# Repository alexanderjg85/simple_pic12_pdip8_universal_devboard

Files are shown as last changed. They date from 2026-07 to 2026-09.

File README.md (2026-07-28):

# simple_pic12_pdip8_universal_devboard
A simple development board with an LED and GPIOs on Pin headers. Includes an ICSP Header and selectable dual power supply with a screw terminal

## Project Structure
- **/hardware**: Contains the KiCad schematic and PCB layout files.
- **/firmware**: Contains the Microchip MPLAB  C/ASM source code.

## Programming Notes
- Designed for all **PIC12 8-PDIP Variants with Flashmemory** microcontrollers.
- Programmed using **Microchip MPLAB** and an **PicKit 2/3** programmer. 
- *Note:* The PicKit Programmer can power the board. Make sure to choose appropriate Voltage 3.3 V or 5V and make sure that the board is jumpered correctly, if powered by external power supply. 

## License / Lizenz

This project is dual-licensed / Dieses Projekt ist dual-lizenziert:

* **Hardware (Schematic, PCB Layout):** Licensed under the [CERN Open Hardware Licence Version 2 - Permissive (CERN-OHL-P)](LICENSE_HARDWARE.md).
* **Software (Firmware, Example Code):** Licensed under the [MIT License](LICENSE).

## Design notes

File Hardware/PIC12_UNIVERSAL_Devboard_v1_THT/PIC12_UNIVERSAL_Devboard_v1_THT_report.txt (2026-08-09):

PCB statistics report
=====================
- Date: Sun 09 Aug 2026 13:23:43 CEST
- Project: PIC12_UNIVERSAL_Devboard_v1_THT
- Board name: PIC12_UNIVERSAL_Devboard_v1_THT

Board
-----
- Width: 70.0000 mm
- Height: 40.0000 mm
- Area: 2800.00 mm²
- Front copper area: 365.793 mm²
- Back copper area: 2592.249 mm²
- Min track clearance: 0.3600 mm
- Min track width: 0.3000 mm
- Min drill diameter: 0.4500 mm
- Board stackup thickness: 1.6000 mm

- Front footprint area: 781.65 mm²
- Back footprint area: 147.625 mm²
- Front component density: 27.92 %
- Back component density: 5.27 %
Pads
----
- Through hole: 34
- SMD: 46
- Connector: 0
- NPTH: 4
- Castellated: 0
- Press-fit: 0

Vias
----
- Through vias: 36
- Blind vias: 0
- Buried vias: 0
- Micro vias: 0

Components
----------

| | Front Side | Back Side | Total |
|---|---|---|---|
|THT: | 7 | 0 | 7 |
|SMD: | 15 | 0 | 15 |
|Unspecified:  | 17 | 0 | 17 |
|Total: | 39 | 0 | 39 |

Drill holes
-----------

| Count | Shape | X Size | Y Size | Plated | Via/Pad | Start Layer | Stop Layer |
|---|---|---|---|---|---|---|---|
| 27 | Round | 0.5000 mm | 0.5000 mm | PTH | Via | F.Cu | B.Cu |
| 16 | Round | 1.0000 mm | 1.0000 mm | PTH | Pad | F.Cu | B.Cu |
| 12 | Round | 0.8000 mm | 0.8000 mm | PTH | Pad | F.Cu | B.Cu |
| 9 | Round | 0.4500 mm | 0.4500 mm | PTH | Via | F.Cu | B.Cu |
| 4 | Round | 2.7000 mm | 2.7000 mm | NPTH | Pad | F.Cu | B.Cu |
| 4 | Round | 0.9000 mm | 0.9000 mm | PTH | Pad | F.Cu | B.Cu |
| 2 | Round | 1.3000 mm | 1.3000 mm | PTH | Pad | F.Cu | B.Cu |

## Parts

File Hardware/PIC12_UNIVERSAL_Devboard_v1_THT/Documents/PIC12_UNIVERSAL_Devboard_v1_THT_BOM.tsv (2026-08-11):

Reference | Qty | Value | Spec | Package | LCSC | MFR PN
C1,C3,C4 | 3 | 1 uF | ±10% 50V | 0805 | C6119929
C2 | 1 | 470nF | ±10% 50V | 0805 | C13967
C5 | 1 | 100nF | ±10% 50V | 0805 | C49678
D1,D4 | 2 | SS14 | 30V 0.5A Schottky Diode | SMA | C2480
D2 | 1 | GREEN | LED GREEN | 3 mm
D3 | 1 | YELLOW | LED YELLOW | 3 mm
J2 | 1 | Conn_PIC_ICSP_ICD | Male / THT/ Vertical | 2.54 mm 1x6
J3 | 1 | Screw_Terminal_01x02 | Horizontal | 5.08mm 1x2
J4 | 1 | Conn_01x07_Pin | Male / THT/ Vertical | 2.54 mm 1x7
JP1 | 1 | JP_PLED | Male / THT/ Vertical | 2.54 mm 1x2
JP2 | 1 | Jumper_3_Open | Male / THT/ Vertical | 2.54 mm 1x3
JP3 | 1 | JP_SLED | Male / THT/ Vertical | 2.54 mm 1x2
R1 | 1 | 680 | 1% 125 mW | 1206
R2,R4 | 2 | 10k | 1% 125 mW | 1206
R3 | 1 | 330 | 1% 125 mW | 1206
SW1 | 1 | SW_RESET | H=4.5mm Tactile | 4.5 x 4.5 SMD |  | SWT0210-045026GSA
U1 | 1 | PIC12F617-xP | 8-Bit PIC 20 Mhz | PDIP-8 |  | PIC12F17I/P
U2 | 1 | 78L05G-AB3-R | 5V 0.1 A | SOT-89-3 | C71136
U3 | 1 | XC6206-3.3V_C3015484 | 3.3V 0.25A | SOT23 | C3015484
U4 | 1 | SI2301-A1SHB | P-Mos 20V 2.3A | SOT23 | C28642376 | SI2301-A1SHB

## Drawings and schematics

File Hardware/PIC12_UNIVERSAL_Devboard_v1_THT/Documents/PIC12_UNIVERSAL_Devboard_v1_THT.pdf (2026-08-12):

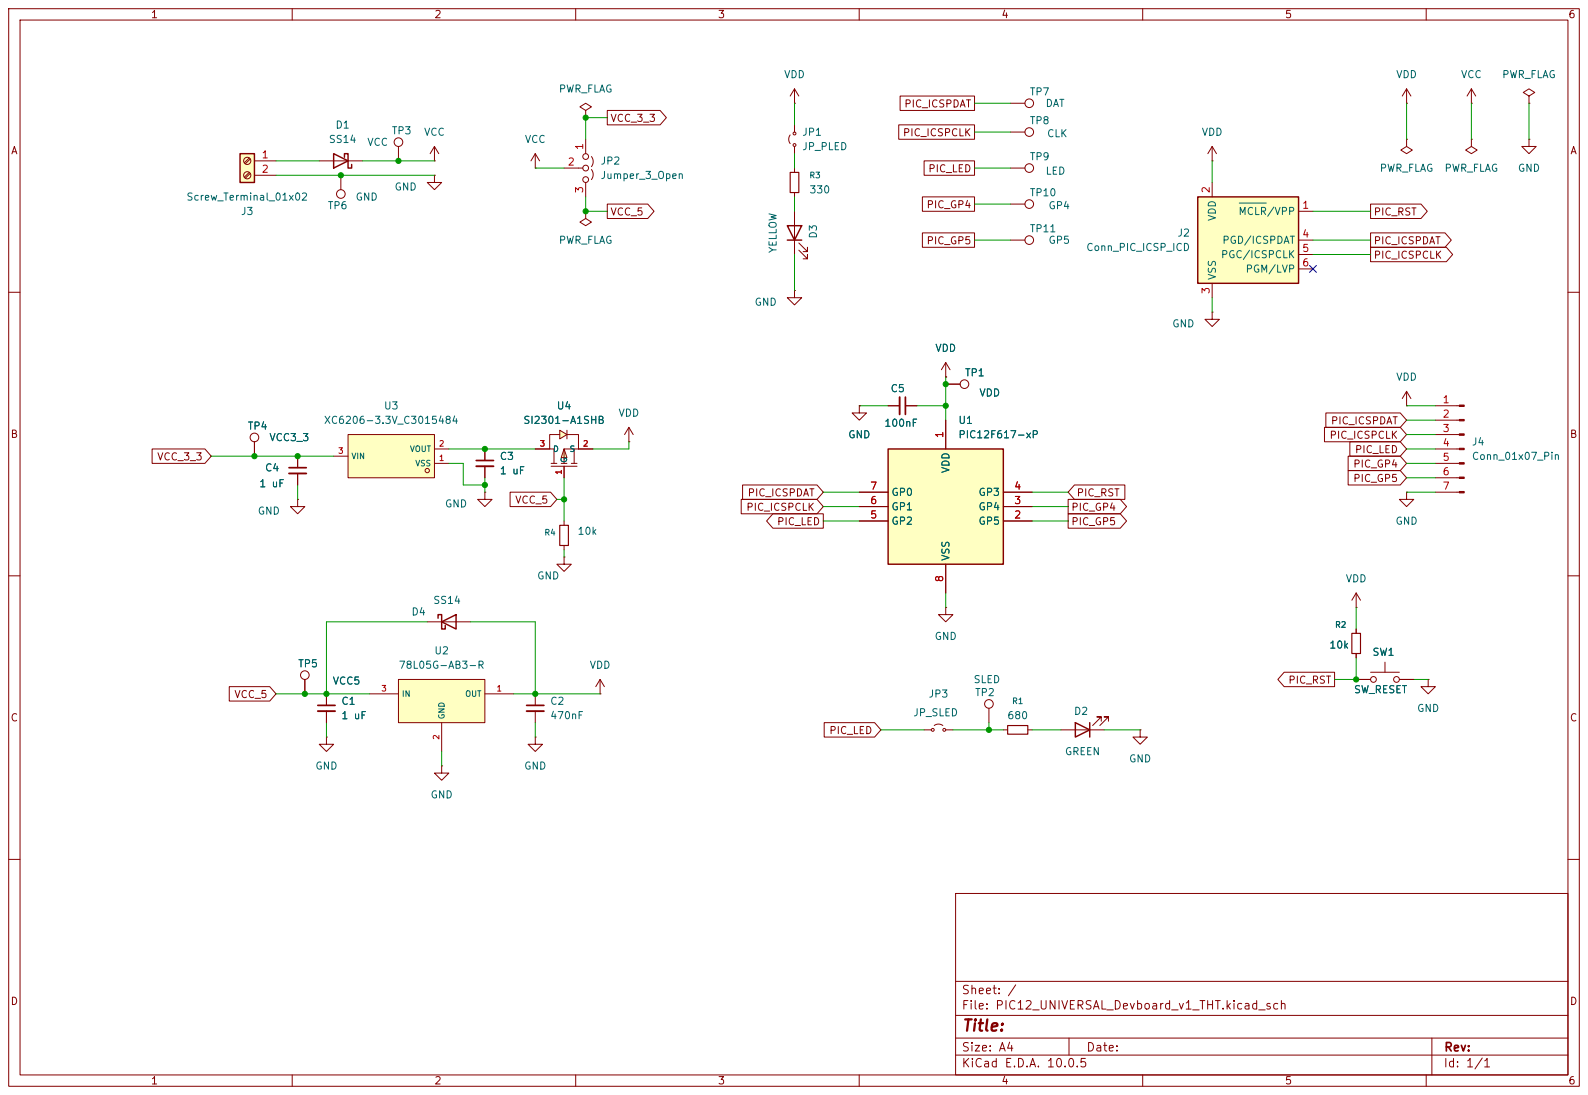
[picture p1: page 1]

3 PGD/ICSPDAT 4 PGC/ICSPCLK 5 PGM/LVP 6

Size: A4 | Rev:
KiCad E.D.A. 10.0.5 | Id: 1/1

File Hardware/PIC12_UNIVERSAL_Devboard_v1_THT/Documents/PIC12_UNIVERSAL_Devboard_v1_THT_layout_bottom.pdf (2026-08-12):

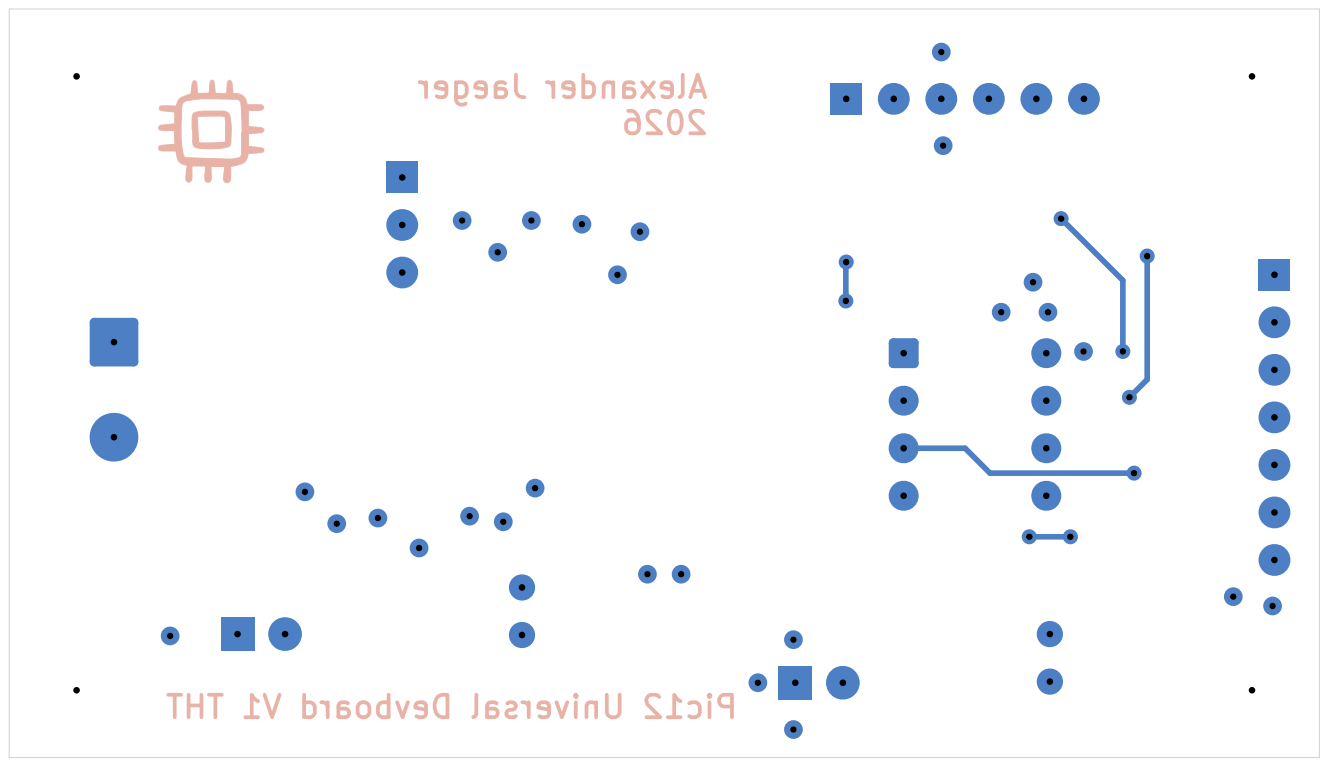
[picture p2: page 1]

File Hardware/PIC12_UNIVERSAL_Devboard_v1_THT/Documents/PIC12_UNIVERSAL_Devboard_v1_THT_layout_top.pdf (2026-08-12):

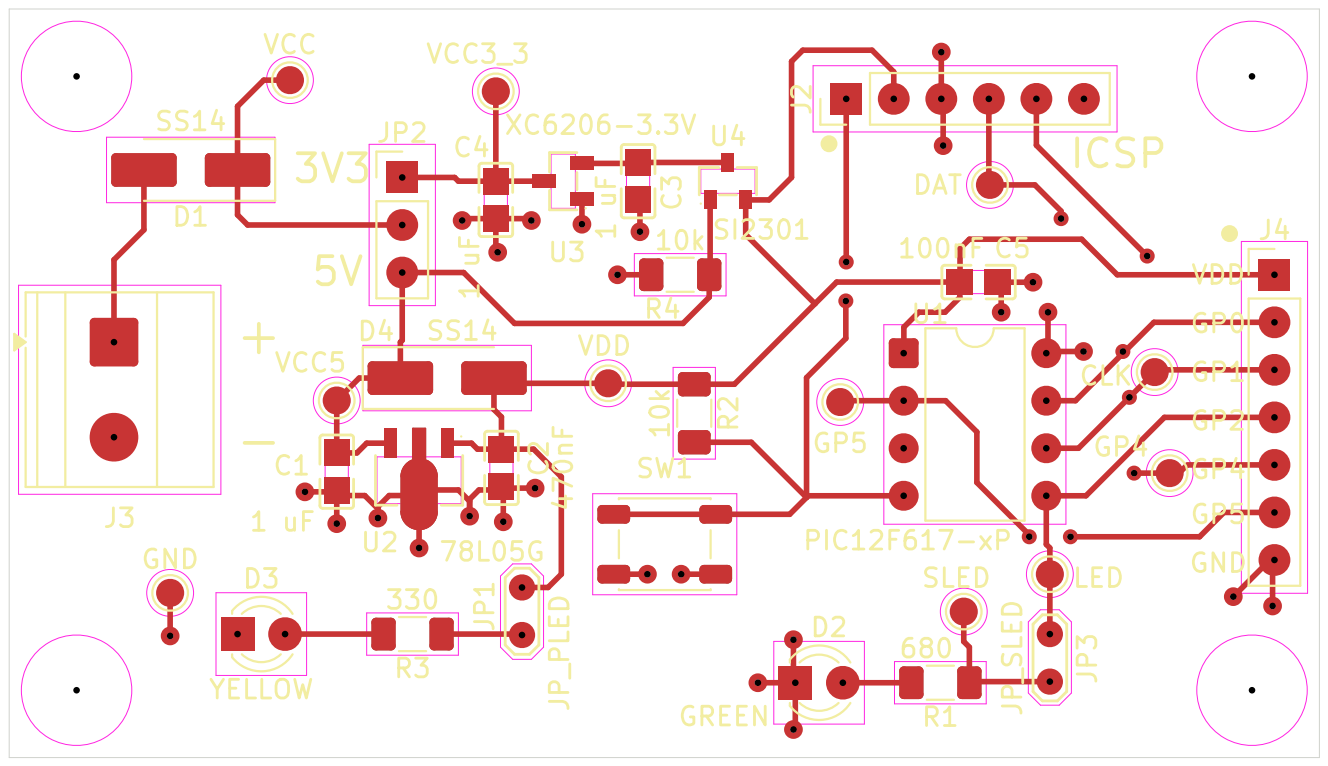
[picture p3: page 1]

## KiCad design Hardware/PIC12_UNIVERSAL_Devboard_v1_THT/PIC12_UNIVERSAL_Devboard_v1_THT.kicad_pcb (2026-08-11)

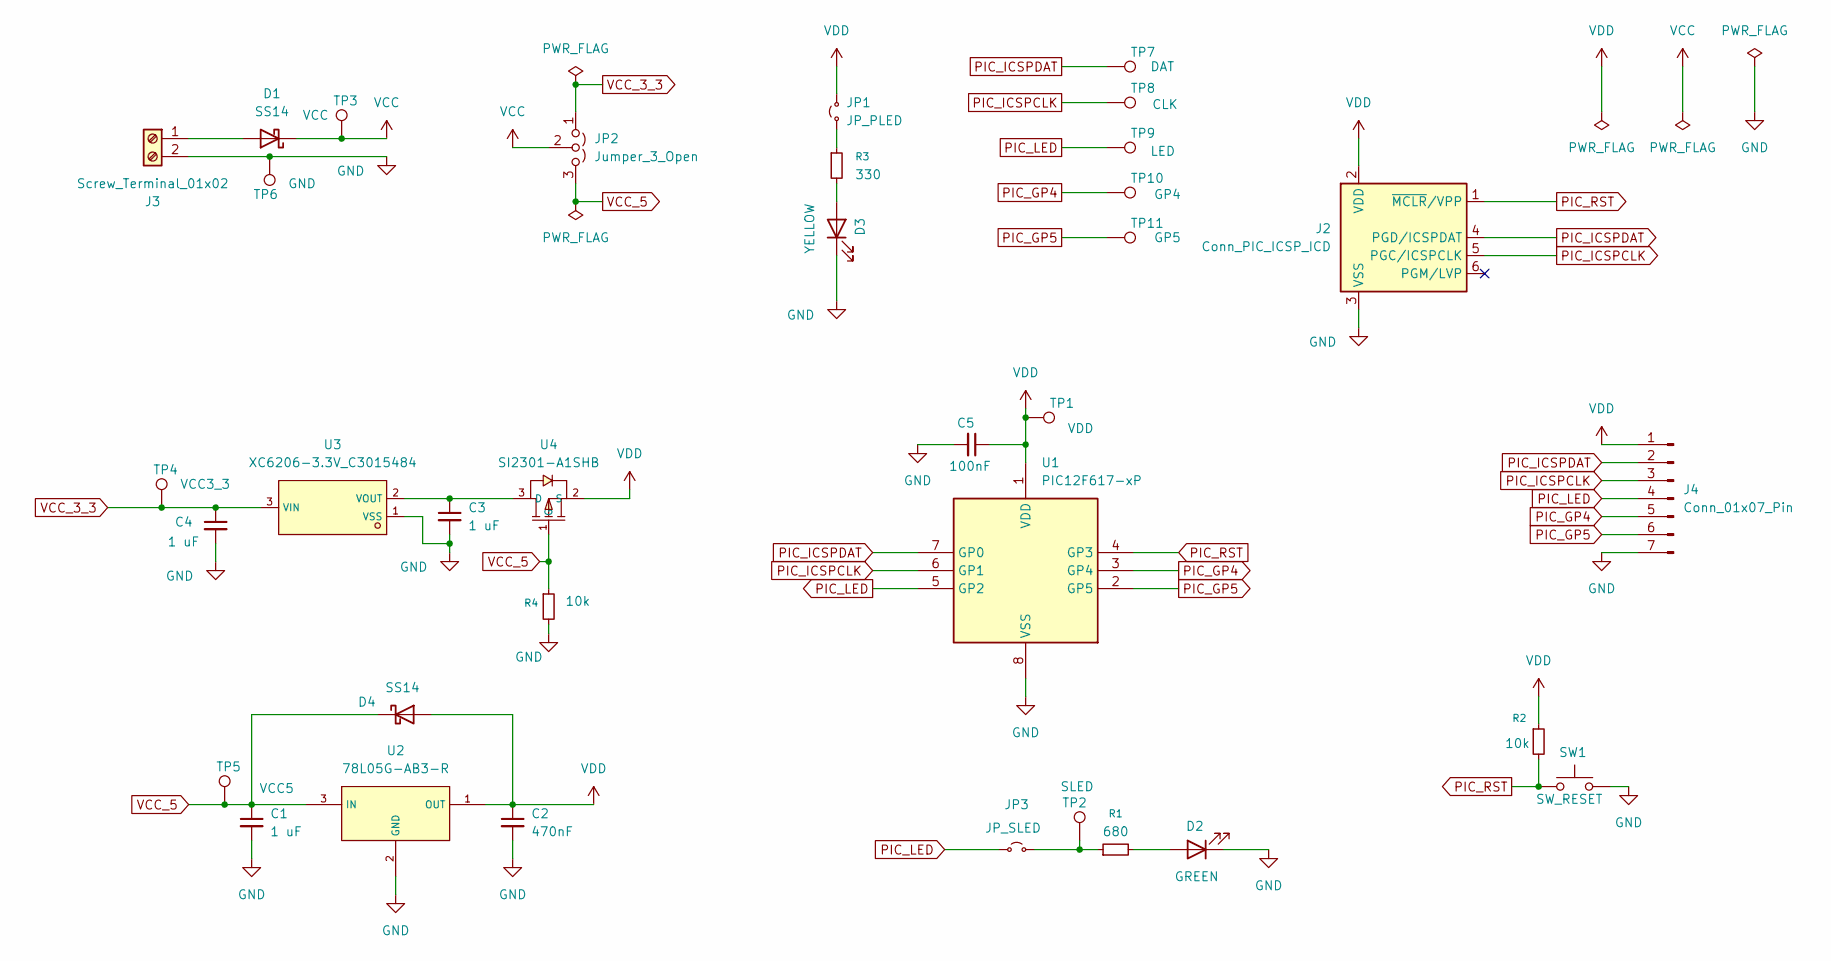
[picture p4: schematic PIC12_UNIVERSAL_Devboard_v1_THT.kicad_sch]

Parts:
C1, C3, C4: 1 uF; C6119929_C0805; LCSC C6119929
C2: 470nF; C13967_C0805; LCSC C13967
C5: 100nF; C49678_C0805; LCSC C49678
D1, D4: SS14; D_SMA_Handsoldering; LCSC C2480
D2: GREEN; LED_D3.0mm
D3: YELLOW; LED_D3.0mm
J2: Conn_PIC_ICSP_ICD; PinHeader_1x06_P2.54mm_Vertical
J3: Screw_Terminal_01x02; TerminalBlock_Phoenix_MKDS-1,5-2-5.08_1x02_P5.08mm_Horizont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
J4: Conn_01x07_Pin; PinHeader_1x07_P2.54mm_Vertical
JP1: JP_PLED; TestPoint_2Pads_Pitch2.54mm_Drill0.8mm
JP2: Jumper_3_Open; PinHeader_1x03_P2.54mm_Vertical
JP3: JP_SLED; TestPoint_2Pads_Pitch2.54mm_Drill0.8mm
R1: 680; R_1206_3216Metric_Pad1.30x1.75mm_HandSolder
R2, R4: 10k; R_1206_3216Metric_Pad1.30x1.75mm_HandSolder
R3: 330; R_1206_3216Metric_Pad1.30x1.75mm_HandSolder
SW1: SW_RESET; SW_SPST_PTS647_Sx38_Handsolder; MFR PN SWT0210-045026GSA
TP1: VDD; TestPoint_Pad_D1.5mm
TP2: SLED; TestPoint_Pad_D1.5mm
TP3: VCC; TestPoint_Pad_D1.5mm
TP4: VCC3_3; TestPoint_Pad_D1.5mm
TP5: VCC5; TestPoint_Pad_D1.5mm
TP6: GND; TestPoint_Pad_D1.5mm
TP7: DAT; TestPoint_Pad_D1.5mm
TP8: CLK; TestPoint_Pad_D1.5mm
TP9: LED; TestPoint_Pad_D1.5mm
TP10: GP4; TestPoint_Pad_D1.5mm
TP11: GP5; TestPoint_Pad_D1.5mm
U1: PIC12F617-xP; DIP-8_W7.62mm; MFR PN PIC12F17I/P
U2: 78L05G-AB3-R; C71136_SOT-89-3_L4_5-W2_5-P1_50-LS4_2-BR; LCSC C71136
U3: XC6206-3.3V_C3015484; C3015484_SOT-23-3_L2_9-W1_3-P0_95-LS2_4-BR; LCSC C3015484
U4: SI2301-A1SHB; C28642376_SOT-23-3_L2_9-W1_3-P1_90-LS2_4-BR; MFR PN SI2301-A1SHB; LCSC C28642376

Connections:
GND: C1.2, C2.2, C3.2, C4.2, C5.2, D2.1 (K), D3.1 (K), J2.3 (VSS), J3.2, J4.7, R4.2, SW1.2, TP6.1 (1_1), U1.8 (VSS), U2.2 (GND), U3.1 (VSS)
unnamed: D1.2 (A), J3.1
unnamed: D2.2 (A), R1.2
unnamed: D3.2 (A), R3.2
unnamed: JP1.1 (A), R3.1
unnamed: JP3.2 (B), R1.1, TP2.1 (1_1)
unnamed: C3.1, U3.2 (VOUT), U4.3 (D)
PIC_GP4: J4.5, TP10.1 (1_1), U1.3 (GP4)
PIC_GP5: J4.6, TP11.1 (1_1), U1.2 (GP5)
PIC_ICSPCLK: J2.5 (PGC/ICSPCLK), J4.3, TP8.1 (1_1), U1.6 (GP1)
PIC_ICSPDAT: J2.4 (PGD/ICSPDAT), J4.2, TP7.1 (1_1), U1.7 (GP0)
PIC_LED: J4.4, JP3.1 (A), TP9.1 (1_1), U1.5 (GP2)
PIC_RST: J2.1 (~MCLR/VPP), R2.2, SW1.1, U1.4 (GP3)
VCC: D1.1 (K), JP2.2 (C), TP3.1 (1_1)
VCC_3_3: C4.1, JP2.1 (A), TP4.1 (1_1), U3.3 (VIN)
VCC_5: C1.1, D4.1 (K), JP2.3 (B), R4.1, TP5.1 (1_1), U2.3 (IN), U4.1 (G)
VDD: C2.1, C5.1, D4.2 (A), J2.2 (VDD), J4.1, JP1.2 (B), R2.1, TP1.1 (1_1), U1.1 (VDD), U2.1 (OUT), U4.2 (S)

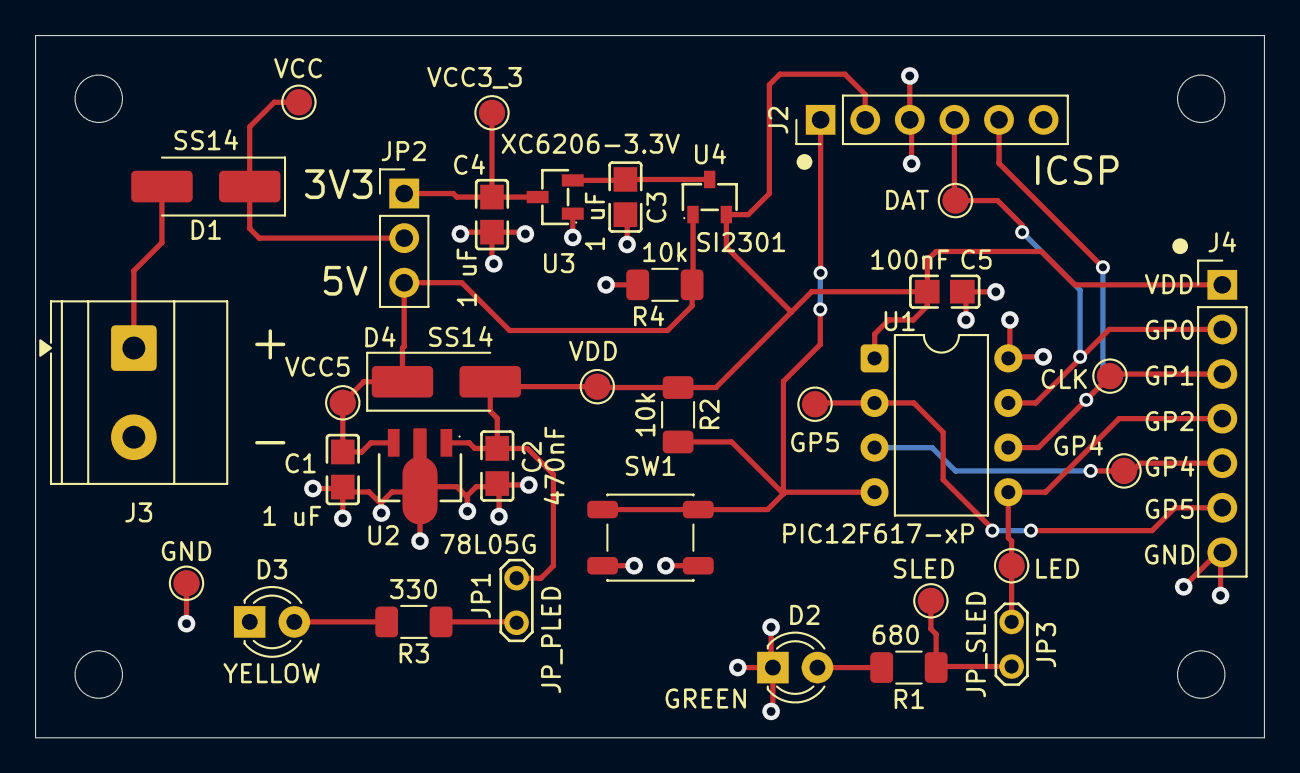
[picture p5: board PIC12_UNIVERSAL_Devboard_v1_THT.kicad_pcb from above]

Board: 2 copper layers, 70.0 x 40.0 mm, 35 parts (0 on the bottom side), 17 nets.

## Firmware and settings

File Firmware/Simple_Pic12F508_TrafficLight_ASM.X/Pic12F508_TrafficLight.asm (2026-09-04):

; **************************************************
; Project: Traffic Light for PIC12F508
; Goal: Let a green, yellow and red LED blink like
;       a traffic light. LED are at Pin GP0,GP1,GP4
; Runs at 4 Mhz, 1 Mhz per instruction cycle
; **************************************************

#include <xc.inc>
    
#define LED_RED	    GPIO,0
#define LED_YELLOW  GPIO,1
#define LED_GREEN   GPIO,4
    
; Configuration:
;       no codeprotection
;       no WDT-Timer
;       no Reset-Pin
;	internal Oszillator 

config CP = OFF
config WDT = OFF
config MCLRE = ON  
config OSC = IntRC
    
;***********************************************************************
; data memory space:   07h - 1FH PIC12F08  

;define Variable names
PSECT udata, class=RAM, space=1
delay_val:     ds 1    ; reload value for the loop counters
delay4_var:    ds 1    ; variable for the inner 4 ms loop
delay1000_var:  ds 1    ; variable for the outer 1000 ms loop
    
;*******************************************************
; Begin programmcode
; GP3-In, GP0-2,GP4,GP5 OUT = 08H
    

;use custom psect to force linker to put this section at the reset vector
PSECT prog_code, abs, ovrld, class=CODE, delta=2

org     0x0000	;necessary otherwise linker puts entry_code section at this address

START: 
    MOVWF   OSCCAL          ; calibrate Oszillator

;Init **********************************************************************
;set variables
;Delay_Variable
    MOVLW 0xFA	;write value FAh (250dec) in W reg
    MOVWF delay_val ; write W into delay_val
 
    ;40H in W, Prescaler assigned to Timer, Prescaler set to 1/2, disable Wake_up on pin change, no Pull-Ups, Timer Transisition on internal clock
    MOVLW	0x40  
    OPTION		;W in Optionregister
 
    CLRF	GPIO	;set all output GPIO values to zero
    MOVLW	0x08	;write 08H to W-Register
    TRIS	GPIO	;write W to TRIS-Register set  GP0-2,3,4 as output
 
 ; Init End ****************************************************************

;*******************************************************
MAIN:
    CALL    LIGHT_RED	    ;Red LED lights for 3 seconds
    CALL    DELAY_1000      ;wait 1000 ms
    CALL    DELAY_1000      ;wait 1000 ms
    CALL    DELAY_1000      ;wait 1000 ms
    CALL    LIGHT_YELLOW_RED  ;wait for one second before turning green
    CALL    DELAY_1000      ;wait 1000 ms
    CALL    LIGHT_GREEN	    ;Red LED lights for 3 seconds
    CALL    DELAY_1000      ;wait 1000 ms
    CALL    DELAY_1000      ;wait 1000 ms
    CALL    DELAY_1000      ;wait 1000 ms
    CALL    LIGHT_YELLOW    ;wait for one second before turning red
    CALL    DELAY_1000      ;wait 1000 ms
 
    GOTO    MAIN
    
;delay loops *******************************************************
PSECT entryCode,class=ENTRY,delta=2
;loop duration 2ms
DELAY_4:
    MOVF delay_val, W	;write value 250 from delay_val to W
    MOVWF delay4_var	;write W to Register delay4_var
DELAY_4_START:		;duration 8 cycles => 16 * 250 = 4 ms delay
    NOP
    NOP
    NOP
    NOP
    NOP
    NOP
    NOP
    NOP
    NOP
    NOP
    NOP
    NOP
    NOP
    DECFSZ delay4_var, F ;delay4_var -= 1
    GOTO DELAY_4_START
    RETLW   0

; delay 1000 ms
DELAY_1000:
    MOVF delay_val, W	;write value 250 from delay_val to W
    MOVWF delay1000_var	; write W to Register delay1000_var
DELAY1000_START:
    Call DELAY_4
    DECFSZ delay1000_var, F ;delay1000_var -= 1
    GOTO DELAY1000_START
    RETLW   0 
    
;functions for the lighting patterns **********************************
;Function LIGHT_GREEN only green LED lights up
LIGHT_GREEN:
    BSF LED_GREEN   ;on
    BCF LED_YELLOW  ;off
    BCF LED_RED	    ;off
    RETLW   0

;Function LIGHT_YELLOW only yellow LED lights up
LIGHT_YELLOW:
    BCF LED_GREEN   ;off
    BSF LED_YELLOW  ;on
    BCF LED_RED	    ;on
    RETLW   0

;Function LIGHT_RED only red LED lights up
LIGHT_RED:
    BCF LED_GREEN   ;off
    BCF LED_YELLOW  ;off
    BSF LED_RED	    ;on
    RETLW   0

;Function LIGHT_YELLOW_RED red and yellow LED lights up
LIGHT_YELLOW_RED:
    BCF LED_GREEN   ;off
    BSF LED_YELLOW  ;on
    BSF LED_RED	    ;on
    RETLW   0

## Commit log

2026-07-28 Added Kicad Project files for PIC12 Universal Dev Board
    [PIC12_UNIVERSAL_Devboard_v1_THT.kicad_pcb, PIC12_UNIVERSAL_Devboard_v1_THT.kicad_sch]
2026-07-28 PIC12 Universal Dev Board - Added PIC12, Headers, Power and Status LED Screw Terminal and Reset Switch to Schematics
    [PIC12_UNIVERSAL_Devboard_v1_THT.kicad_sch]
2026-07-29 PIC12 Universal Dev Board - Schematics - Changed Footprint of the LEDs
    [PIC12_UNIVERSAL_Devboard_v1_THT.kicad_sch]
2026-08-01 PIC12 Universal Dev Board - Schematics - Added remaining components
    [PIC12_UNIVERSAL_Devboard_v1_THT.kicad_sch]
2026-08-02 PIC12 Universal Dev Board - Schematics - Finished Schematics
    [PIC12_UNIVERSAL_Devboard_v1_THT.kicad_sch]
2026-08-03 PIC12 Universal Dev Board - Schematics - Added Testpoints
    [PIC12_UNIVERSAL_Devboard_v1_THT.kicad_sch]
2026-08-03 PIC12 Universal Dev Board - Layout - Added JLCPCB Design Rules
    [PIC12_UNIVERSAL_Devboard_v1_THT.kicad_pcb]
2026-08-03 PIC12 Universal Dev Board - Schematics - Added Footprint for Jumper2
    [PIC12_UNIVERSAL_Devboard_v1_THT.kicad_sch]
2026-08-03 PIC12 Universal Dev Board - Schematics - Changed Footprint of ICSP Header Layout - Defined Egde Cut, Imported Components from schematics
    [PIC12_UNIVERSAL_Devboard_v1_THT.kicad_pcb, PIC12_UNIVERSAL_Devboard_v1_THT.kicad_sch]
2026-08-05 IC12 Universal Dev Board - Added Datasheets
2026-08-05 PIC12 Universal Dev Board - Schematics - Added Reverse Current Protection Diode for 78L05 Regulator
    [PIC12_UNIVERSAL_Devboard_v1_THT.kicad_sch]
2026-08-06 PIC12 Universal Dev Board - Schematics - Added Reverse Current Protection PMOS for XC6240 Regulator
    [PIC12_UNIVERSAL_Devboard_v1_THT.kicad_sch]
2026-08-06 IC12 Universal Dev Board - Layout - Finished Initial Component Placement
    [PIC12_UNIVERSAL_Devboard_v1_THT.kicad_pcb]
2026-08-07 PIC12 Universal Dev Board - Layout - Finished Routing
    [PIC12_UNIVERSAL_Devboard_v1_THT.kicad_pcb]
2026-08-08 PIC12 Universal Dev Board - Layout - Finished Silk Screen
    [PIC12_UNIVERSAL_Devboard_v1_THT.kicad_pcb]
2026-08-08 PIC12 Universal Dev Board - Hardware - Added Gerber Files
    [PIC12_UNIVERSAL_Devboard_v1_THT-B_Cu.gbr, PIC12_UNIVERSAL_Devboard_v1_THT-B_Mask.gbr, PIC12_UNIVERSAL_Devboard_v1_THT-B_Paste.gbr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]
2026-08-09 PIC12 Universal Dev Board - Schematics - Added Part Properties
    [PIC12_UNIVERSAL_Devboard_v1_THT.kicad_sch]
2026-08-09 PIC12 Universal Dev Board - Added BOM and Board Statistics
    [PIC12_UNIVERSAL_Devboard_v1_THT_BOM.tsv]
2026-08-11 PIC12 Universal Dev Board - Updated Reset Switch Footprint for better Handsoldering
    [PIC12_UNIVERSAL_Devboard_v1_THT.kicad_pcb, PIC12_UNIVERSAL_Devboard_v1_THT.kicad_sch]
2026-08-11 PIC12 Universal Dev Board - Updated BOM
    [PIC12_UNIVERSAL_Devboard_v1_THT_BOM.tsv]
2026-08-12 PIC12 Universal Dev Board - Added Schematic and Board Layout PDFs
2026-09-01 PIC12 Universal Dev Board - updated gitignore
2026-09-01 PIC12 Universal Dev Board - Software - Added PIC12F508 Blinky Led Assembler Project
2026-09-02 PIC12 Universal Dev Board - Software - PIC12F508 Blinky Led Assembler corrected some comments
    [Pic12F508_BlinkyLED.asm]
2026-09-04 PIC12 Universal Dev Board - Software - Added PIC12F508 Traffic Light Assembler Project
2026-09-09 PIC12 Universal Dev Board - Added XC8 Assembler User Guides
